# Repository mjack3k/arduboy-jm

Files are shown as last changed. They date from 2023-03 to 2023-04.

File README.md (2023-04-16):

# Arduboy JM
My homebrew clone of arduboy - arduino-based handheld game console

<p float="left">
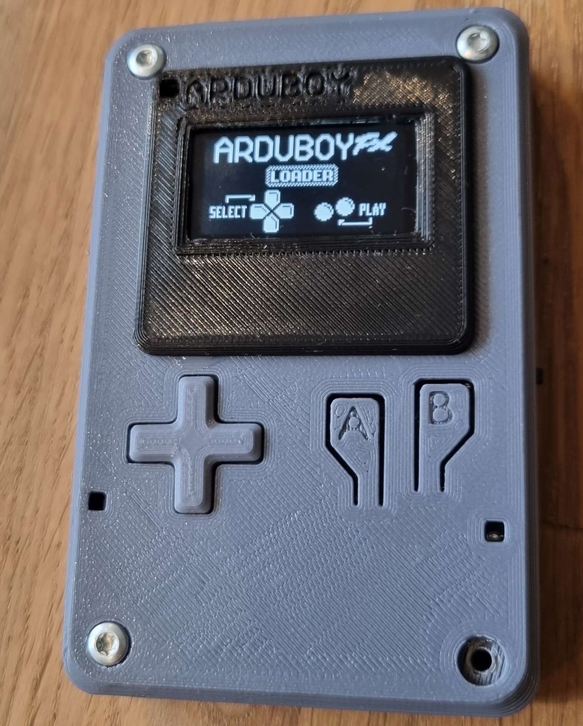
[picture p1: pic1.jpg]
    
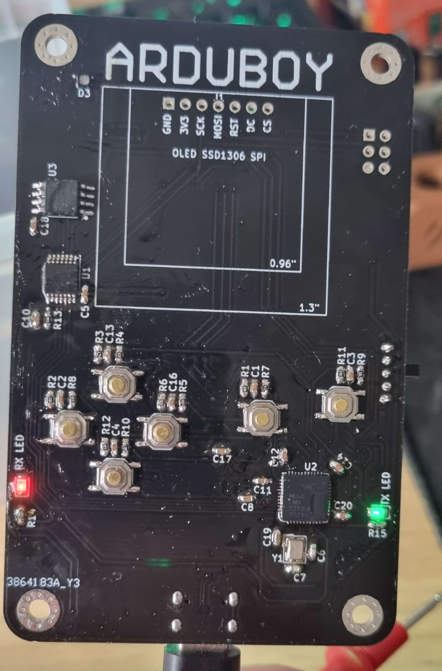
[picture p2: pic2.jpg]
    
</p>

For the original Arduboy please visit [their website](https://www.arduboy.com/)
<br/>
<br/>

## Description
This project differs a bit from the official arduboy. 
It follows the alternate **Pro Micro 5V alternate wiring**.
All buttons have pull-up resistors and debounce filter (resistor + capacitor).

Battery charging and 5V boost circuit is also a bit over-engineered - I stole that part from my other project idea that was meant for powering raspberry pi.
In theory it could deliver over 3A, if proper LiPo battery was used. 

It is a bit bigger - no longer credit-card sized, but I believe it makes it more comfortable to use. 

And since we're in 2023 already, I used USB-C connector instead of microUSB.
Also added ESD-protection IC on the USB port. 

This arduboy has the **FX-Mod** on board - a SPI-Flash chip to hold all the games.

<br/><br/>
## How to make one?
+ Install [KICAD](https://www.kicad.org/), open the project and generate gerber files (there are guides on how to do it depending on the manufacturer).

+ Order the PCB (I ordered mine at [JCLPCB](https://jlcpcb.com/), no issues so far).

+ Order the parts (all parts* are available at LCSC, but you can source your parts at different suppliers).

+ Solder everything together.

+ Flash the bootloader [*arduboy3k-bootloader-menu-promicro-sh1106.hex*](https://github.com/MrBlinky/cathy3k/tree/main/cathy3k)
<br/>You will need avr isp programmer for that, like [AVRISP MKII](https://www.microchip.com/en-us/development-tool/ATAVRISP2), [USBASP](https://www.fischl.de/usbasp/) or [Arduino as ISP](https://docs.arduino.cc/built-in-examples/arduino-isp/ArduinoISP) and [AVRDUDE](https://github.com/mariusgreuel/avrdude/releases) installed.
<br/>Flash the bootloader with following command (replace COM port and path to .hex file accordingly):
`avrdude -v -p m32u4 -c avrisp -B 22 -b 19200 -P COM4 -U flash:w:arduboy3k-bootloader-game-promicro-sh1106.hex:i`
+ Flash the flashcart 
<br/>This part is tricky, since it involves recompiling all games. On one hand, thanks to great people at arduboy.com, we are able to compile games for different hardware thanks to Homemade package.
<br/>On other hand, arduino IDE is a **BAD** IDE and it is tricky to automate the process (doing it by hand is annoying, since there are 300? 400? games available). 
    + Install [Arduino](https://www.arduino.cc/en/software) and [Homemade Package](https://github.com/MrBlinky/Arduboy-homemade-package)
    + Download [Python Utilities from MrBlinky](https://github.com/MrBlinky/Arduboy-Python-Utilities) (for building flashcard image)
    + Download game source (look for github repositories [here](http://www.bloggingadeadhorse.com/cart/Cart.html))
    + Set board settings like on the picture
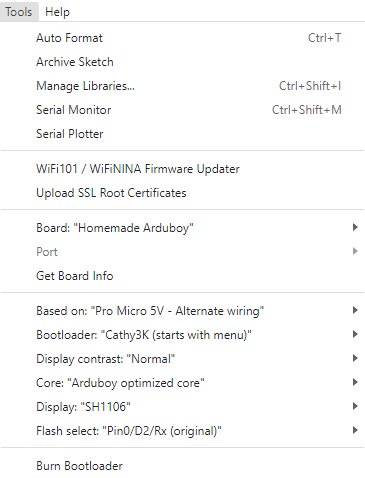
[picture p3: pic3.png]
    <br/>
    + Place the compiled .hex file in directory structure (check example from Python Utilities)
    + Build flashcart ([how](https://github.com/MrBlinky/Arduboy-Python-Utilities#flash-cart-builder))
    + Download [this project](https://github.com/MrBlinky/Arduboy-FX-mod-chip) to get GUI uploader - extract zip from `portable-activator`
    + Select your .bin file and click `Upload Flash image`

<br/>

## Future
In the future I intend to work more on the software side of thise project.
Mainly, I wish to automate the build process, so a script would gather all the games, compile them, place in flashcart directory, generate CSV file and provide a complete BIN for the FX-Mod without manual labor.

<br/>

### Display
I used cheaper SH1106 (SPI) display, but if you get ssd1306 then change your settings to fit (also get different bootloader file).

<br/>

### Battery charging circuit warning
Charging current is related to capacity of the battery. 
Please change the R28 resistor accordingly if you are using smaller LiPos, cause they might not like 500mA charging current. I wouldn't set it to higher current either, cause then it might not work when connected to PC (you will connect to your PC to flash the games).

<br/><br/><br/>
*all parts besides LiPo battery, piezo speaker and display
<br/>Best source for display is ebay, aliexpress or your local online shop for makers.
Speakers can be extracted from old hardware, otherwise similar like display.
LiPo batteries are best bought from local shops, cause they dont want to send them by air, and the prices might vary greatly depending on your location. 
<br/>
Also, you choose the battery you are okay with - differents shapes and sizes available. The project will work even with pretty small batteries, but nothing stops you from putting really big one if you want it.

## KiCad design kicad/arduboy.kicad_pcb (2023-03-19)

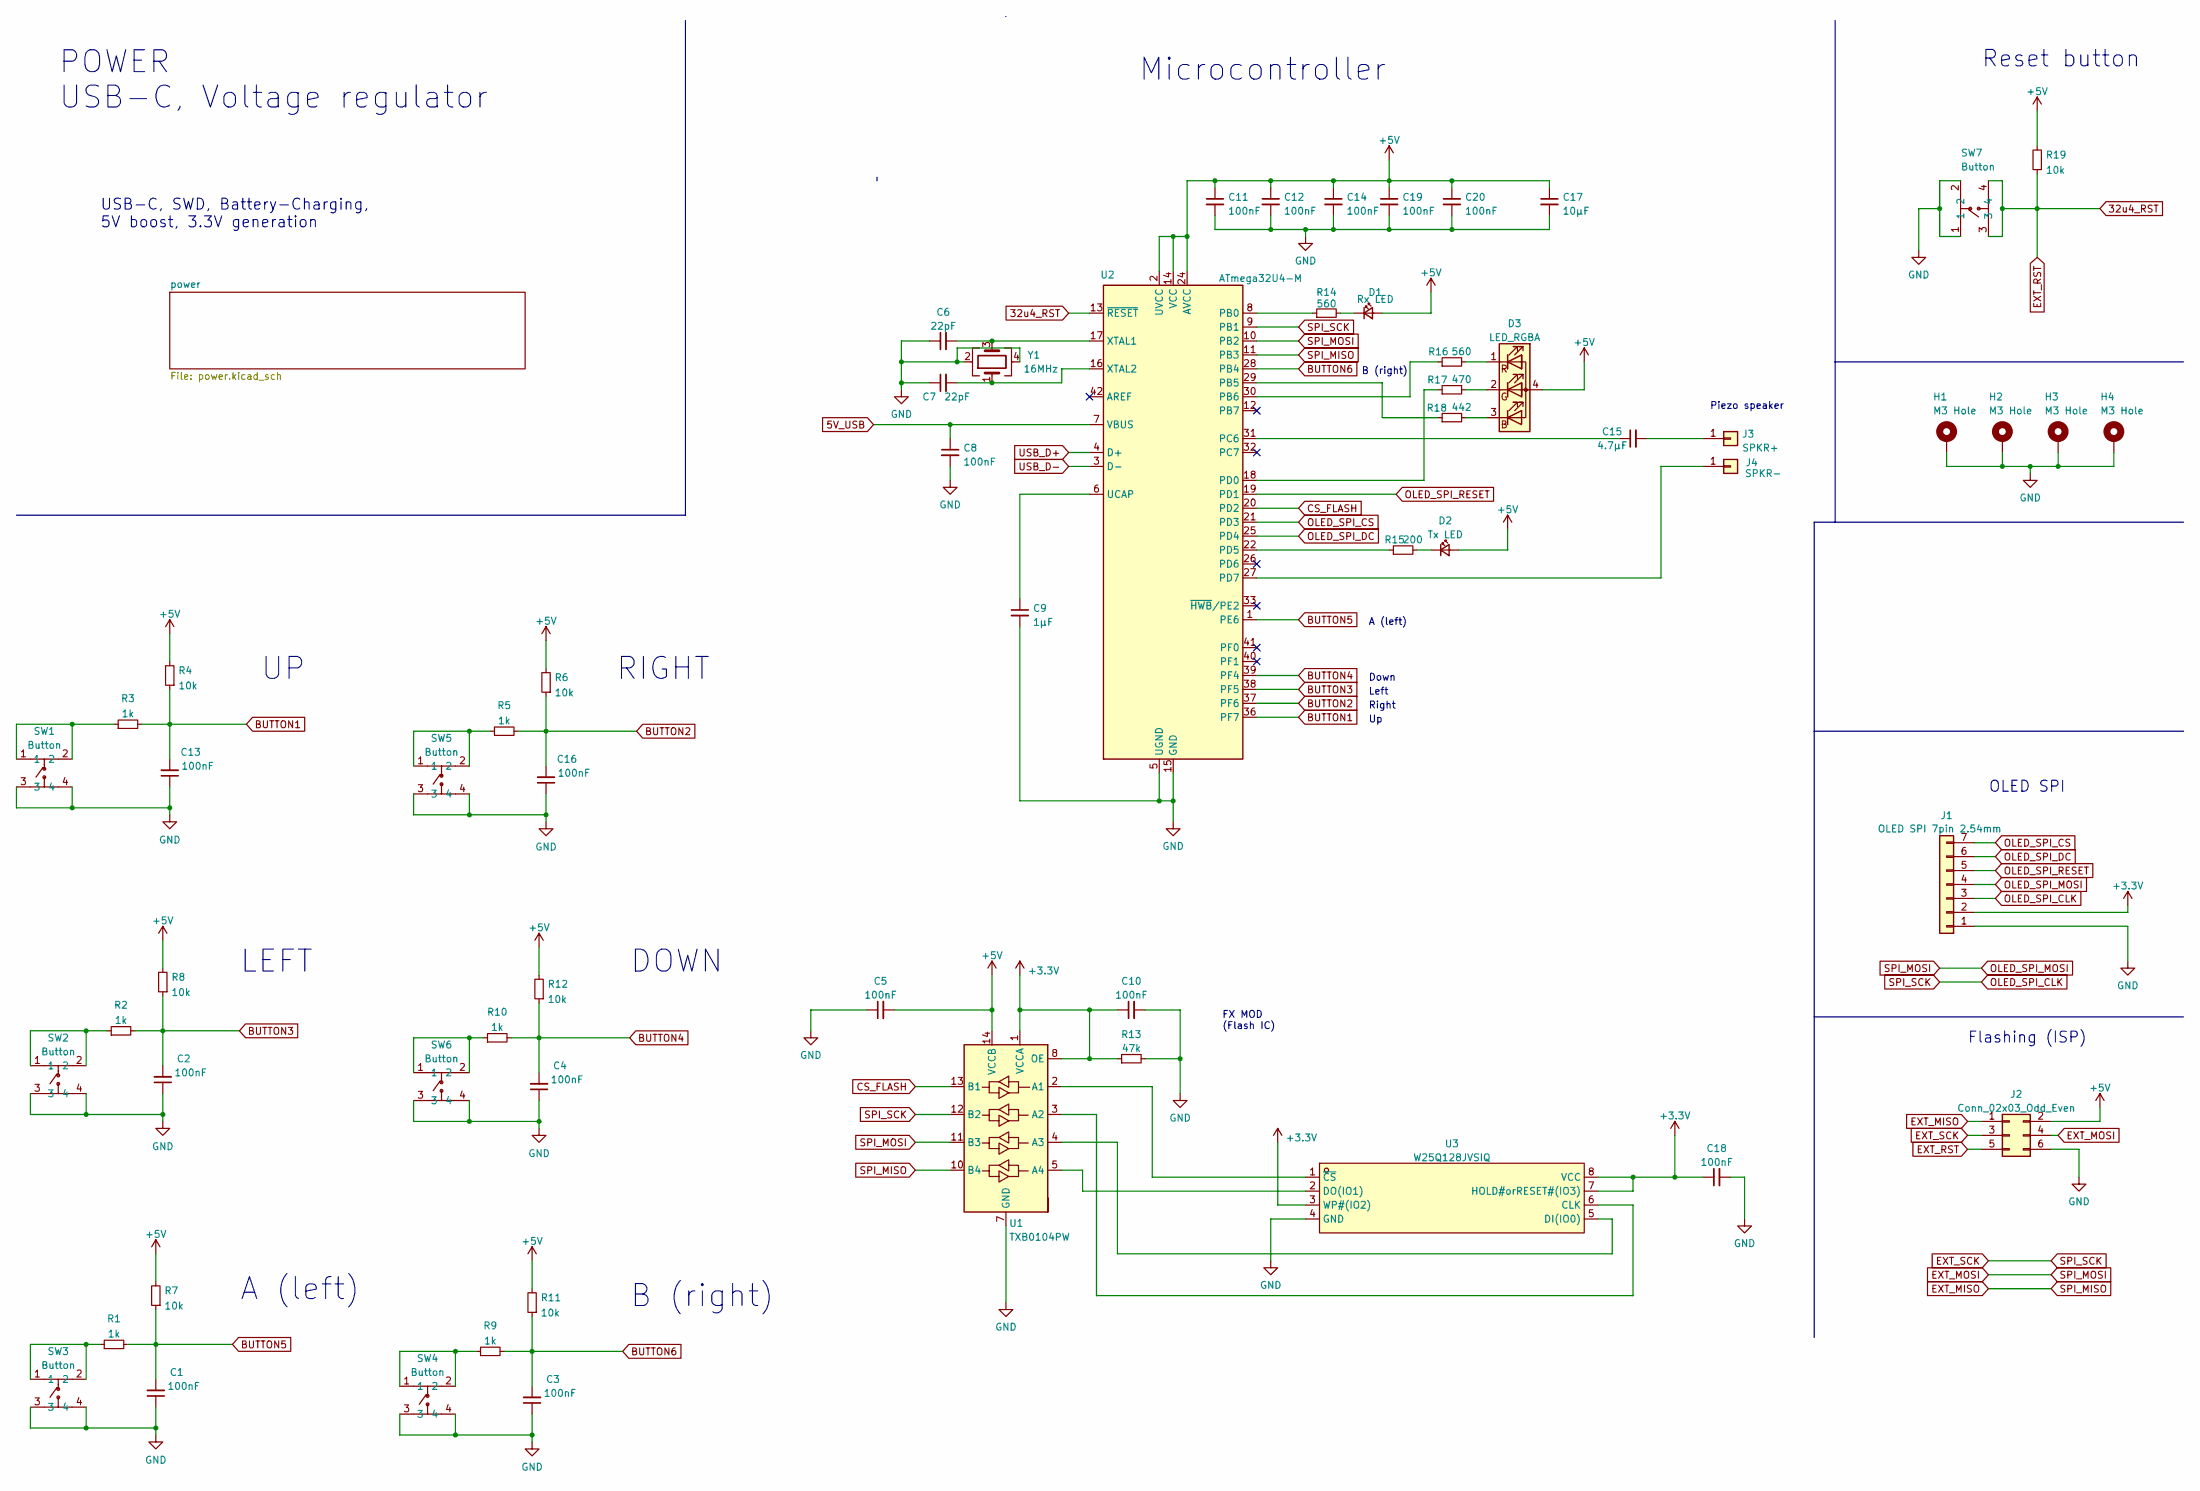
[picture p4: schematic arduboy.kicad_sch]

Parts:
C1, C2, C3, C4, C5, C8, C10, C11, C12, C13, C14, C16, C18, C19, C20: 100nF; C_0603_1608Metric_Pad1.08x0.95mm_HandSolder
C6, C7: 22pF; C_0603_1608Metric_Pad1.08x0.95mm_HandSolder
C9: 1µF; C_0603_1608Metric_Pad1.08x0.95mm_HandSolder
C15: 4.7µF; C_0603_1608Metric
C17: 10µF; C_0603_1608Metric_Pad1.08x0.95mm_HandSolder
D1: Rx LED; LED_0805_2012Metric_Pad1.15x1.40mm_HandSolder
D2: Tx LED; LED_0805_2012Metric_Pad1.15x1.40mm_HandSolder
D3: LED_RGBA; LED-ARRAY-SMD_4P-L2.1-W2.1-TL_NH-B2020RGBA
H1, H2, H3, H4: M3 Hole; MountingHole_3.2mm_M3_Pad_Via
J1: OLED SPI 7pin 2.54mm; OLED_7_Pin
J2: Conn_02x03_Odd_Even; PinSocket_2x03_P2.54mm_Vertical
J3: SPKR+; TestPoint_Pad_4.0x4.0mm
J4: SPKR-; TestPoint_Pad_4.0x4.0mm
R1, R2, R3, R5, R9, R10: 1k; R_0603_1608Metric_Pad0.98x0.95mm_HandSolder
R4, R6, R7, R8, R11, R12, R19: 10k; R_0603_1608Metric_Pad0.98x0.95mm_HandSolder
R13: 47k; R_0603_1608Metric_Pad0.98x0.95mm_HandSolder
R14, R16: 560; R_0603_1608Metric_Pad0.98x0.95mm_HandSolder
R15: 200; R_0603_1608Metric_Pad0.98x0.95mm_HandSolder
R17: 470; R_0603_1608Metric_Pad0.98x0.95mm_HandSolder
R18: 442; R_0603_1608Metric_Pad0.98x0.95mm_HandSolder
SW1, SW2, SW3, SW4, SW5, SW6, SW7: Button; SW-SMD_4P-L5.2-W5.2-P3.70-LS6.4; LCSC Part C2888878
U1: TXB0104PW; TSSOP-14_4.4x5mm_P0.65mm
U2: ATmega32U4-M; QFN-44-1EP_7x7mm_P0.5mm_EP5.2x5.2mm
U3: W25Q128JVSIQ; SOIC-8_L5.3-W5.3-P1.27-LS8.0-BL; LCSC Part C113767
Y1: 16MHz; CRYSTAL-SMD_4P-L3.2-W2.5-BL

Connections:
5V_USB: C8.1, U2.7 (VBUS); also elsewhere on the board
32u4_RST: J2.5, R19.1, SW7.3, SW7.4, U2.13 (~RESET)
+3.3V: C10.1, C18.1, J1.2, R13.1, U1.1 (VCCA), U1.8 (OE), U3.3 (WP#(IO2)), U3.7 (HOLD#orRESET#(IO3)), U3.8 (VCC); also elsewhere on the board
+5V: C5.2, C11.1, C12.1, C14.1, C17.1, C19.1, C20.1, D1.2 (A), D2.2 (A), D3.4 (A), J2.2, R4.2, R6.2, R7.2, R8.2, R11.2, R12.2, R19.2, U1.14 (VCCB), U2.2 (UVCC), U2.14 (VCC), U2.24 (AVCC), U2.34 (VCC), U2.44 (AVCC); also elsewhere on the board
BUTTON1: C13.2, R3.2, R4.1, U2.36 (PF7)
BUTTON2: C16.2, R5.2, R6.1, U2.37 (PF6)
BUTTON3: C2.2, R2.2, R8.1, U2.38 (PF5)
BUTTON4: C4.2, R10.2, R12.1, U2.39 (PF4)
BUTTON5: C1.2, R1.2, R7.1, U2.1 (PE6)
BUTTON6: C3.2, R9.2, R11.1, U2.28 (PB4)
CS_FLASH: U1.13 (B1), U2.20 (PD2)
EXT_MISO: J2.1, U1.10 (B4), U2.11 (PB3)
EXT_MOSI: J1.4, J2.4, U1.11 (B3), U2.10 (PB2)
EXT_SCK: J1.3, J2.3, U1.12 (B2), U2.9 (PB1)
GND: C1.1, C2.1, C3.1, C4.1, C5.1, C6.1, C7.1, C8.2, C9.2, C10.2, C11.2, C12.2, C13.1, C14.2, C16.1, C17.2, C18.2, C19.2, C20.2, H1.1, H2.1, H3.1, H4.1, J1.1, J2.6, R13.2, SW1.3, SW1.4, SW2.3, SW2.4, SW3.3, SW3.4, SW4.3, SW4.4, SW5.3, SW5.4, SW6.3, SW6.4, SW7.1, SW7.2, U1.7 (GND), U2.5 (UGND), U2.15 (GND), U2.23 (GND), U2.35 (GND), U2.43 (GND), U2.45 (GND), U3.4 (GND), Y1.2, Y1.4; also elsewhere on the board
unnamed: C6.2, U2.17 (XTAL1), Y1.3
unnamed: C7.2, U2.16 (XTAL2), Y1.1
unnamed: C9.1, U2.6 (UCAP)
unnamed: C15.1, U2.31 (PC6)
unnamed: C15.2, J3.1
unnamed: D1.1 (K), R14.2
unnamed: D2.1 (K), R15.2
unnamed: D3.1 (RK), R16.2
unnamed: D3.2 (GK), R17.2
unnamed: D3.3 (BK), R18.2
unnamed: R1.1, SW3.1, SW3.2
unnamed: R2.1, SW2.1, SW2.2
unnamed: R3.1, SW1.1, SW1.2
unnamed: R5.1, SW5.1, SW5.2
unnamed: R9.1, SW4.1, SW4.2
unnamed: R10.1, SW6.1, SW6.2
unnamed: R14.1, U2.8 (PB0)
unnamed: R15.1, U2.22 (PD5)
unnamed: R16.1, U2.30 (PB6)
unnamed: R17.1, U2.18 (PD0)
unnamed: R18.1, U2.29 (PB5)
unnamed: U1.2 (A1), U3.1 (~CS)
unnamed: U1.3 (A2), U3.6 (CLK)
unnamed: U1.4 (A3), U3.5 (DI(IO0))
unnamed: U1.5 (A4), U3.2 (DO(IO1))
unnamed: J4.1, U2.27 (PD7)
OLED_SPI_CS: J1.7, U2.21 (PD3)
OLED_SPI_DC: J1.6, U2.25 (PD4)
OLED_SPI_RESET: J1.5, U2.19 (PD1)
USB_D+: U2.4 (D+); also elsewhere on the board
USB_D-: U2.3 (D-); also elsewhere on the board

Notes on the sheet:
Reset button
Right
Piezo speaker
Left
Microcontroller
LEFT
B (right)
POWER USB-C, Voltage regulator
Down
A (left)
FX MOD (Flash IC)
RIGHT
USB-C, SWD, Battery-Charging, 5V boost, 3.3V generation
Flashing (ISP)
OLED SPI
DOWN

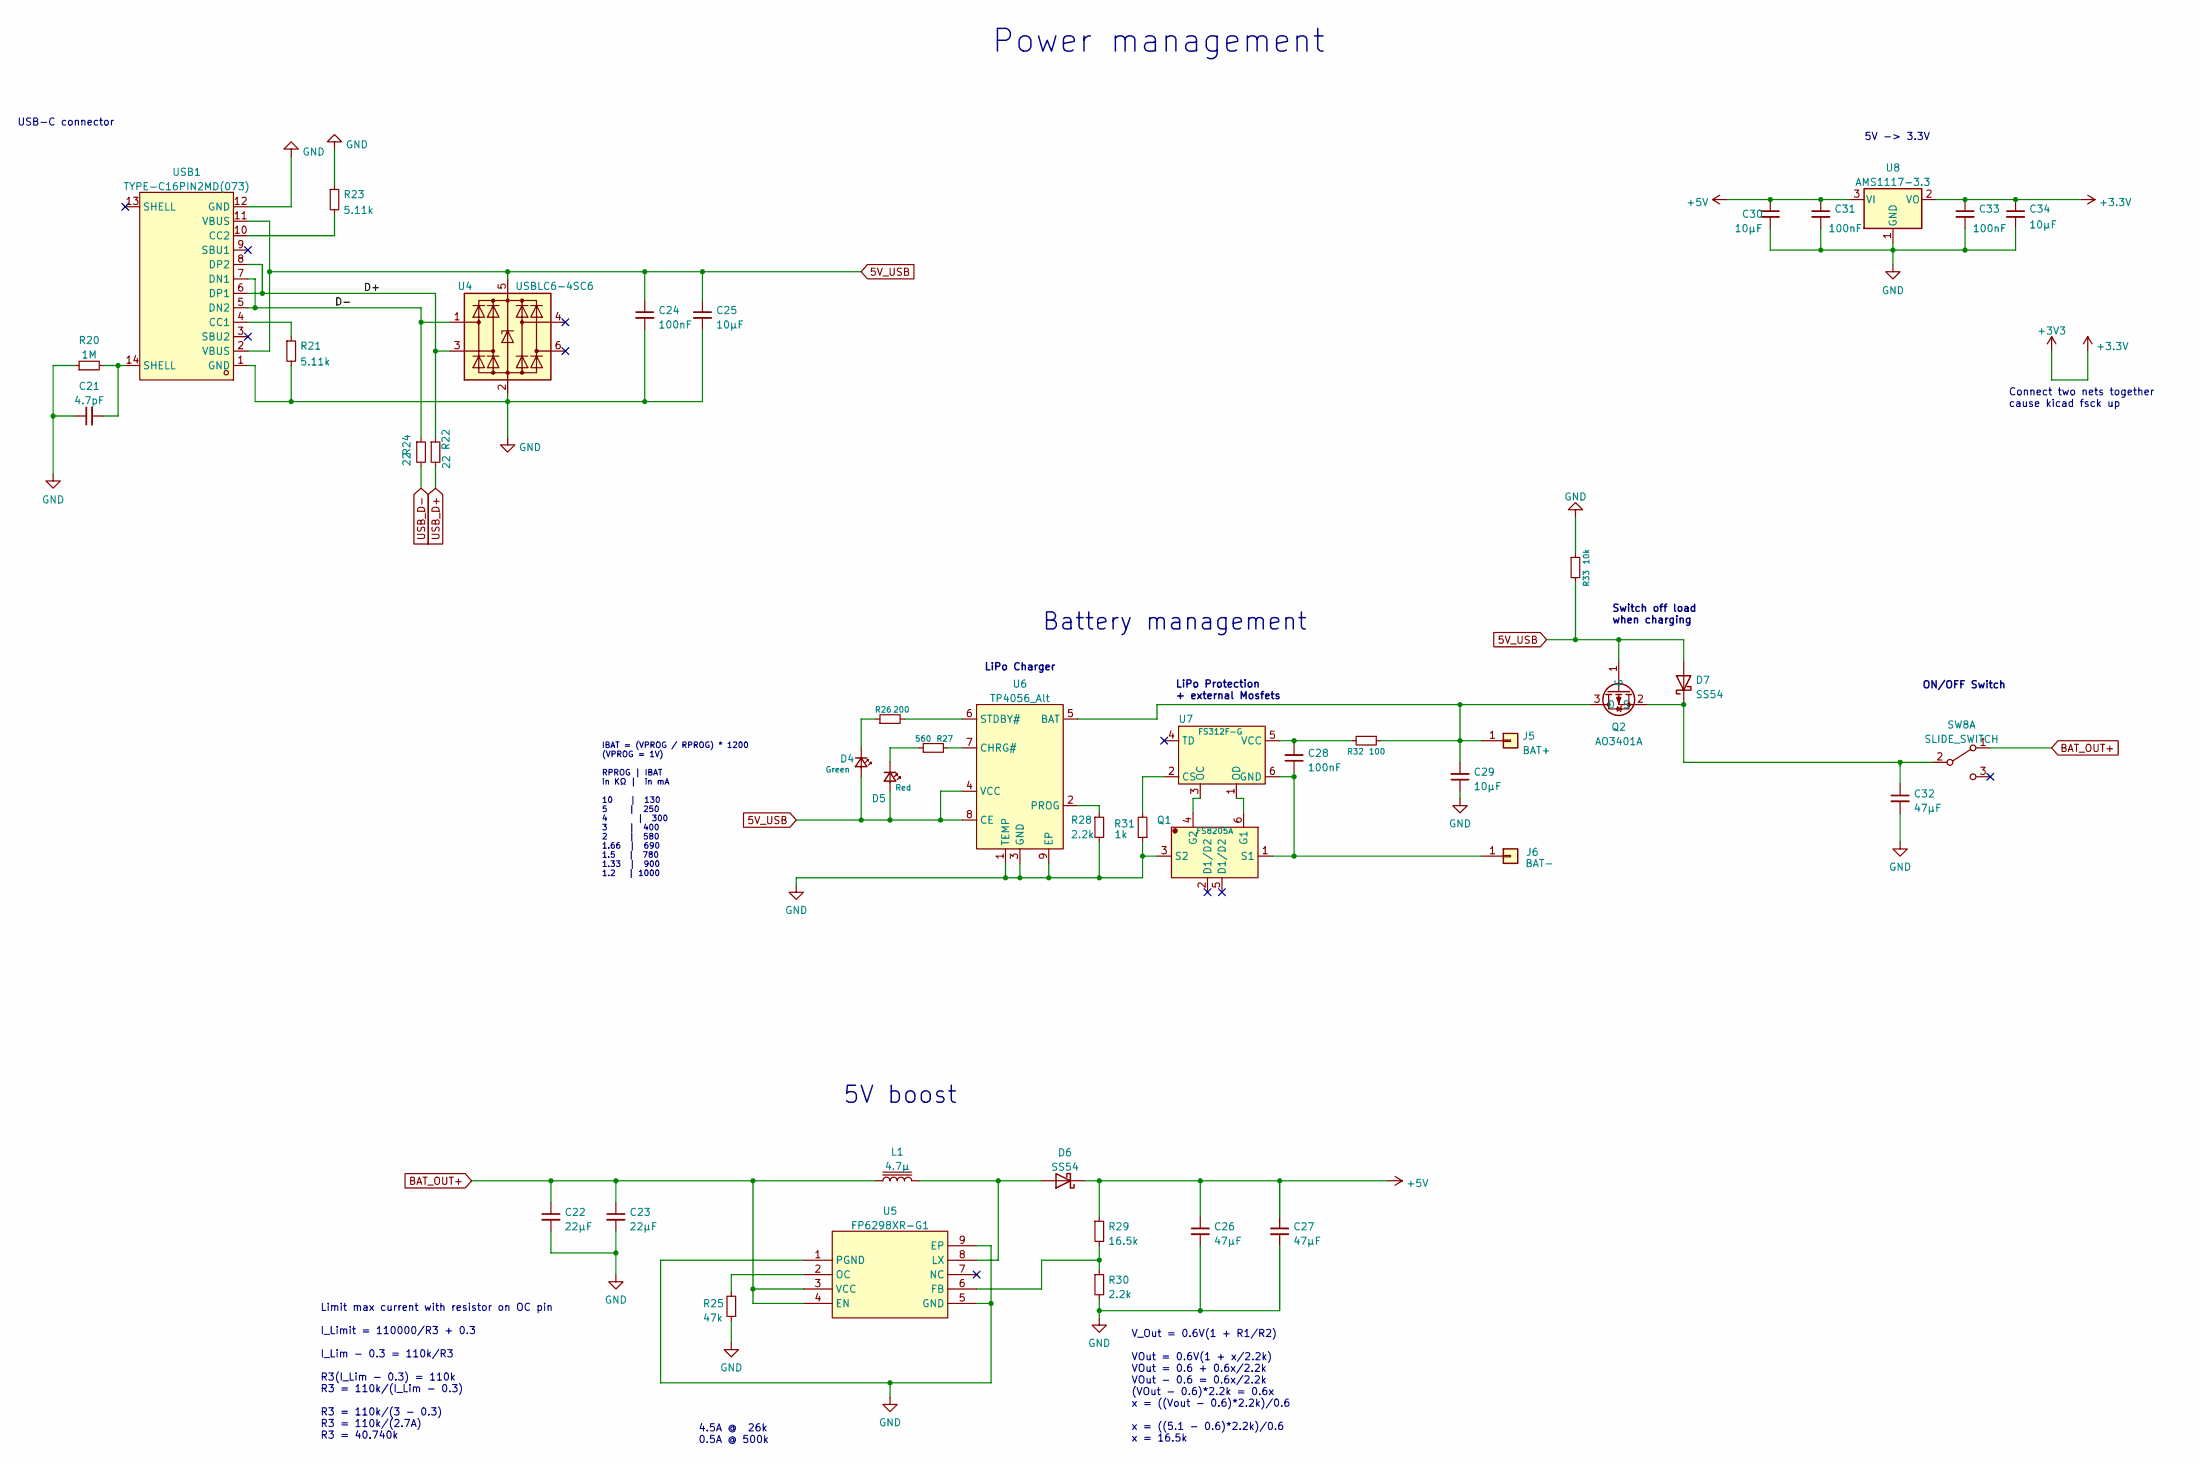
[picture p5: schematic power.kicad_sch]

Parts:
C21: 4.7pF; C_0603_1608Metric_Pad1.08x0.95mm_HandSolder
C22, C23: 22µF; C_0603_1608Metric_Pad1.08x0.95mm_HandSolder
C24, C28, C31, C33: 100nF; C_0603_1608Metric_Pad1.08x0.95mm_HandSolder
C25, C29, C30, C34: 10µF; C_0603_1608Metric_Pad1.08x0.95mm_HandSolder
C26, C27, C32: 47µF; C_1210_3225Metric_Pad1.33x2.70mm_HandSolder
D4: Green; LED_0805_2012Metric_Pad1.15x1.40mm_HandSolder
D5: Red; LED_0805_2012Metric_Pad1.15x1.40mm_HandSolder
D6, D7: SS54; SMA_L4.4-W2.8-LS5.4-R-RD
J5: BAT+; TestPoint_Pad_4.0x4.0mm
J6: BAT-; TestPoint_Pad_4.0x4.0mm
L1: 4.7µ; IND-SMD_L7.3-W6.6
Q1: FS8205A; SOT-23-6_L2.9-W1.6-P0.95-LS2.8-BR
Q2: AO3401A; SOT-23_L2.9-W1.3-P1.90-LS2.4-BR
R20: 1M; R_0603_1608Metric_Pad0.98x0.95mm_HandSolder
R21, R23: 5.11k; R_0603_1608Metric_Pad0.98x0.95mm_HandSolder
R22, R24: 22; R_0603_1608Metric_Pad0.98x0.95mm_HandSolder
R25: 47k; R_0603_1608Metric_Pad0.98x0.95mm_HandSolder
R26: 200; R_0603_1608Metric_Pad0.98x0.95mm_HandSolder
R27: 560; R_0603_1608Metric_Pad0.98x0.95mm_HandSolder
R28, R30: 2.2k; R_0603_1608Metric_Pad0.98x0.95mm_HandSolder
R29: 16.5k; R_0603_1608Metric_Pad0.98x0.95mm_HandSolder
R31: 1k; R_0603_1608Metric_Pad0.98x0.95mm_HandSolder
R32: 100; R_0603_1608Metric_Pad0.98x0.95mm_HandSolder
R33: 10k; R_0603_1608Metric_Pad0.98x0.95mm_HandSolder
SW8: SLIDE_SWITCH; SW-TH_SK-12D07-X-X
U4: USBLC6-4SC6; SOT-23-6
U5: FP6298XR-G1; SOP-8_L4.9-W3.9-P1.27-LS6.0-BL-EP; LCSC Part C88319
U6: TP4056_Alt; ESOP-8_L4.9-W3.9-P1.27-LS6.0-BL-EP
U7: FS312F-G; SOT-23-6_L2.9-W1.6-P0.95-LS2.8-BR
U8: AMS1117-3.3; SOT-223_L6.5-W3.5-P2.30-LS7.0-BR
USB1: TYPE-C16PIN2MD(073); USB-C-SMD_TYPE-C-6PIN-2MD-073; LCSC Part C2765186

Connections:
5V_USB: C24.1, C25.1, D4.2 (A), D5.2 (A), D7.2 (A), Q2.1 (G), R33.2, U4.5 (VBUS), U6.4 (VCC), U6.8 (CE), USB1.2 (VBUS), USB1.11 (VBUS); also elsewhere on the board
+3.3V: C33.1, C34.1, U8.2 (VO); also elsewhere on the board
+5V: C26.1, C27.1, C30.1, C31.1, D6.1 (K), R29.1, U8.3 (VI); also elsewhere on the board
/power/D+: R22.1, U4.3 (I/O2), USB1.6 (DP1), USB1.8 (DP2)
/power/D-: R24.1, U4.1 (I/O1), USB1.5 (DN2), USB1.7 (DN1)
BAT_OUT+: C22.1, C23.1, L1.1, SW8.1 (A), U5.3 (VCC), U5.4 (EN)
GND: C21.1, C22.2, C23.2, C24.2, C25.2, C26.2, C27.2, C29.1, C30.2, C31.2, C32.2, C33.2, C34.2, Q1.3 (S2), R20.1, R21.2, R23.1, R25.1, R28.2, R30.2, R31.1, R33.1, U4.2 (GND), U5.1 (PGND), U5.5 (GND), U5.9 (EP), U6.1 (TEMP), U6.3 (GND), U6.9 (EP), U8.1 (GND), USB1.1 (GND), USB1.12 (GND); also elsewhere on the board
unnamed: C21.2, R20.2, USB1.14 (SHELL)
unnamed: C28.1, J6.1, Q1.1 (S1), U7.6 (GND)
unnamed: C28.2, R32.2, U7.5 (VCC)
unnamed: C29.2, J5.1, Q2.3 (D), R32.1, U6.5 (BAT)
unnamed: C32.1, D7.1 (K), Q2.2 (S), SW8.2 (B)
unnamed: D4.1 (K), R26.1
unnamed: D5.1 (K), R27.1
unnamed: D6.2 (A), L1.2, U5.8 (LX)
unnamed: Q1.4 (G2), U7.3 (OC)
unnamed: Q1.6 (G1), U7.1 (OD)
unnamed: R21.1, USB1.4 (CC1)
unnamed: R23.2, USB1.10 (CC2)
unnamed: R25.2, U5.2 (OC)
unnamed: R26.2, U6.6 (STDBY#)
unnamed: R27.2, U6.7 (CHRG#)
unnamed: R28.1, U6.2 (PROG)
unnamed: R29.2, R30.1, U5.6 (FB)
unnamed: R31.2, U7.2 (CS)
USB_D+: R22.2; also elsewhere on the board
USB_D-: R24.2; also elsewhere on the board

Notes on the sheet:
ON/OFF Switch
Battery management
Switch off load when charging
V_Out = 0.6V(1 + R1/R2) VOut = 0.6V(1 + x/2.2k) VOut = 0.6 + 0.6x/2.2k VOut - 0.6 = 0.6x/2.2k (VOut - 0.6)*2.2k = 0.6x x = ((Vout - 0.6)*2.2k)/0.6 x = ((5.1 - 0.6)*2.2k)/0.6 x = 16.5k
Connect two nets together cause kicad fsck up
5V boost
USB-C connector
Power management
5V -> 3.3V
LiPo Protection + external Mosfets
LiPo Charger
4.5A @ 26k 0.5A @ 500k
Limit max current with resistor on OC pin I_Limit = 110000/R3 + 0.3 I_Lim - 0.3 = 110k/R3 R3(I_Lim - 0.3) = 110k R3 = 110k/(I_Lim - 0.3) R3 = 110k/(3 - 0.3) R3 = 110k/(2.7A) R3 = 40.740k
IBAT = (VPROG / RPROG) * 1200 (VPROG = 1V) RPROG | IBAT in KΩ | in mA 10 | 130 5 | 250 4 | 300 3 | 400 2 | 580 1.66 | 690 1.5 | 780 1.33 | 900 1.2 | 1000

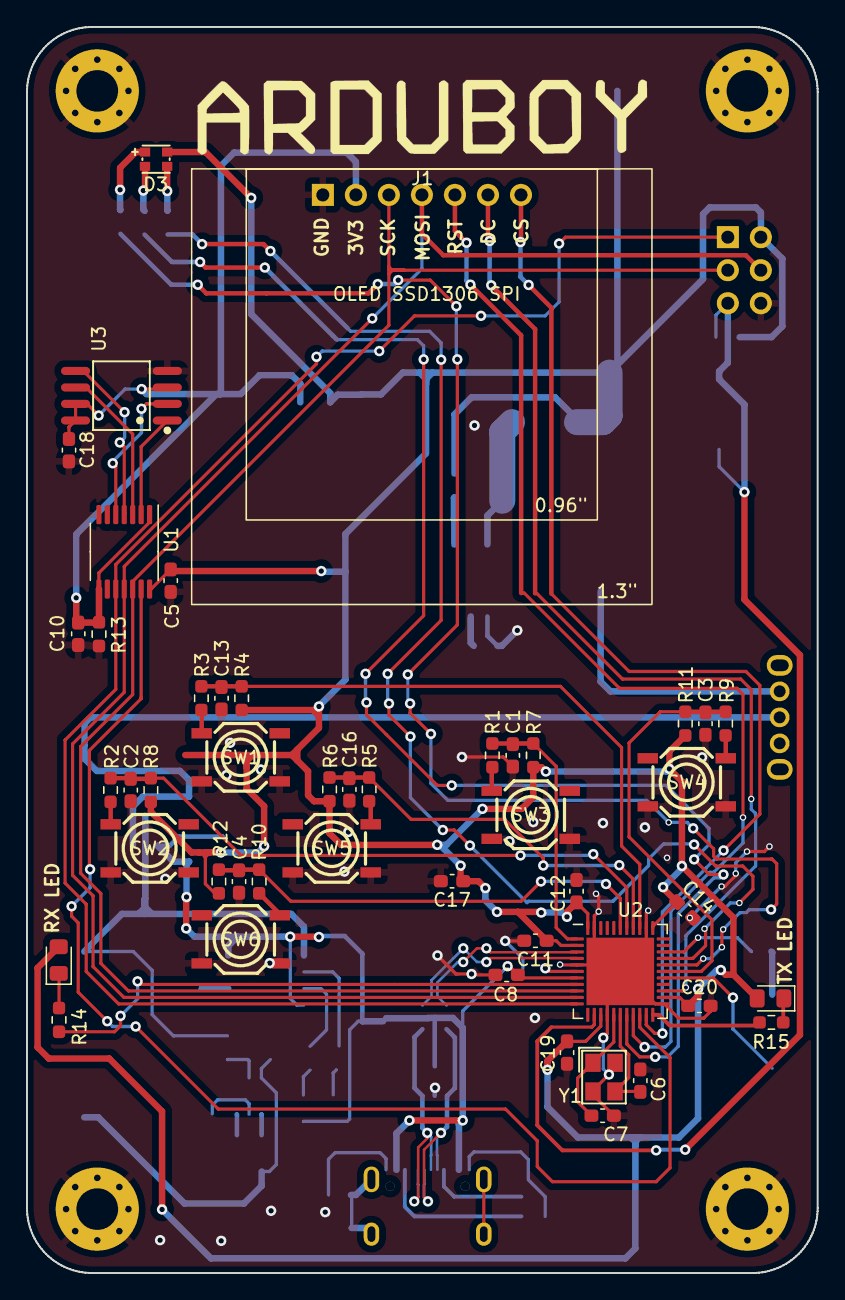
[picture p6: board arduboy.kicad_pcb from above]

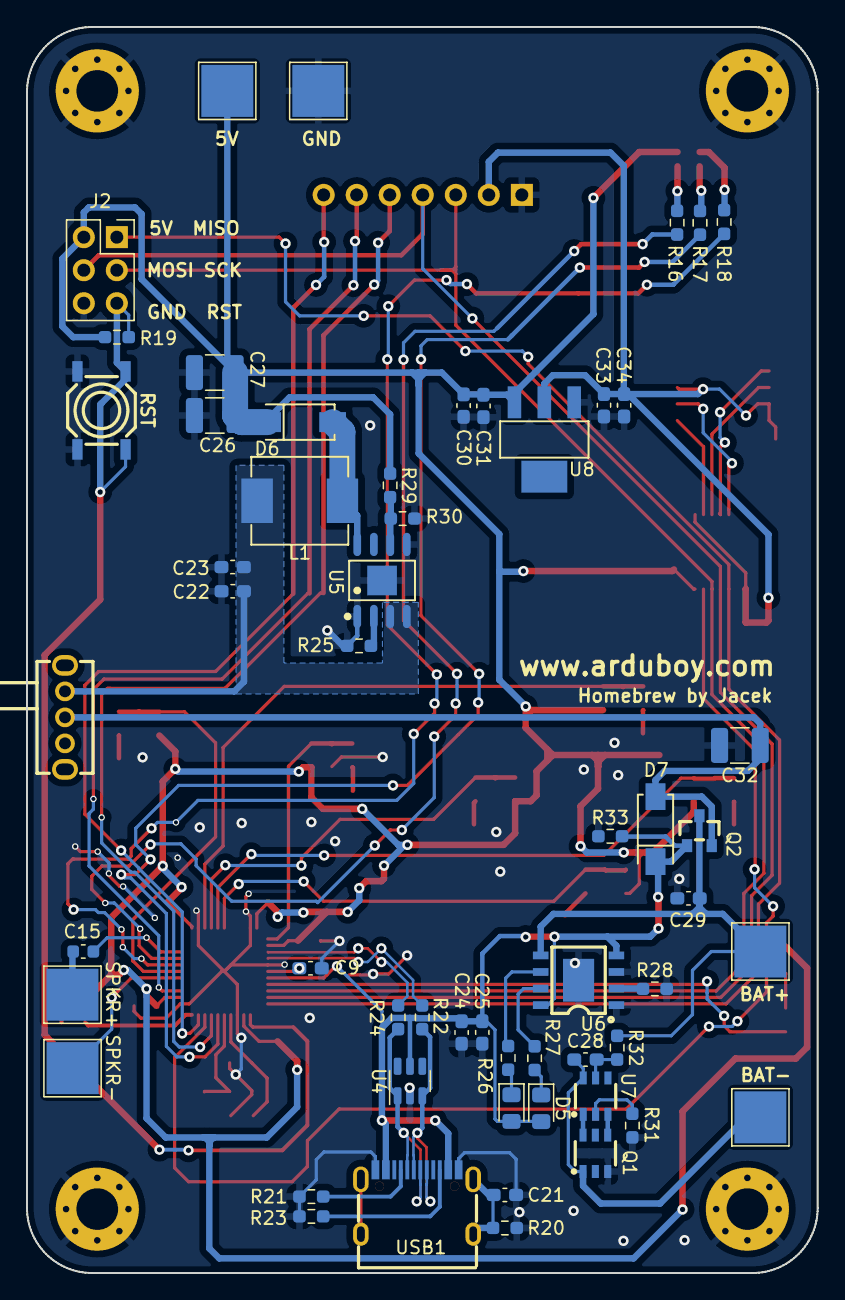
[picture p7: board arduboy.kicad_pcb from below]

Board: 2 copper layers, 60.8 x 95.8 mm, 105 parts (54 on the bottom side), 67 nets.
